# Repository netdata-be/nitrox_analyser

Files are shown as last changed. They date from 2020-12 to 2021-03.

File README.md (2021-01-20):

# Nitrox Anylyser

## BOM 

| # | Name | Price  |
|---|---|---|
| 1 | PCB custom made |  9,99  |
| 1 | Arduino Nano | 19,00  |
| 1 | ADS1115 | 14,95  |
| 1 | 1.3 inch OLED Display 128*64 pixels wit - I2C |  8,00  |
| 1 | MT3608 DC-DC Boost converter |  2,00  |
| 1 | Diode 1N4007 |  0,10  |
| 1 | 18650 Battery holder to solder |  1,50  |
| 1 | 18650 Battery with protection |  6,50  |
| 1 | Audio Jack 3,5mm (mono) 0,6m |  1,50  |
| 1 | 40 Pin header row |  0,40  |
| 1 | [O2 oxygen Cell (R-17VAN Oxygen Sensor) or other](https://www.vandagraph.com/index.php?main_page=product_info&cPath=5_8&products_id=30) | 79,00  |
| 1 | Spelsberg Kabeldoos abox 060-62 | 12,00  |
| 1 | On/Off button |  2,50  |
| 1 | Push Button |  2,50  |
| 1 | [B-50057 Flow Diverter](https://www.vandagraph.com/index.php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) |  5,00  |
| 1 | [Quick-Ox Sampler](https://www.vandagraph.com/index.php?main_page=product_info&products_id=20) | 22,00  |

Total cost: 194,95

The sensor, flow divertor, and Quick-Ox are high end quality products as they are needed for an accurate measurement.

## Functions 

* Auto calibrate iteself at boot to 20.9 oxygen
* Force a calibration by long pressing the button
* When measuring 100% o2 and forcing a calibration by a long press a second calibration point is stored ( 20,9% air ADN 100% ) 
  so compensating for the not fully linear scale.
* Each press on the button gives you an other page with info
  This page is saved to eeprom so if you shutdown and restart the analyzer the last page selected will be shown again.
* Battery monitor of the 18650 battery

## Screenshots of the different screens

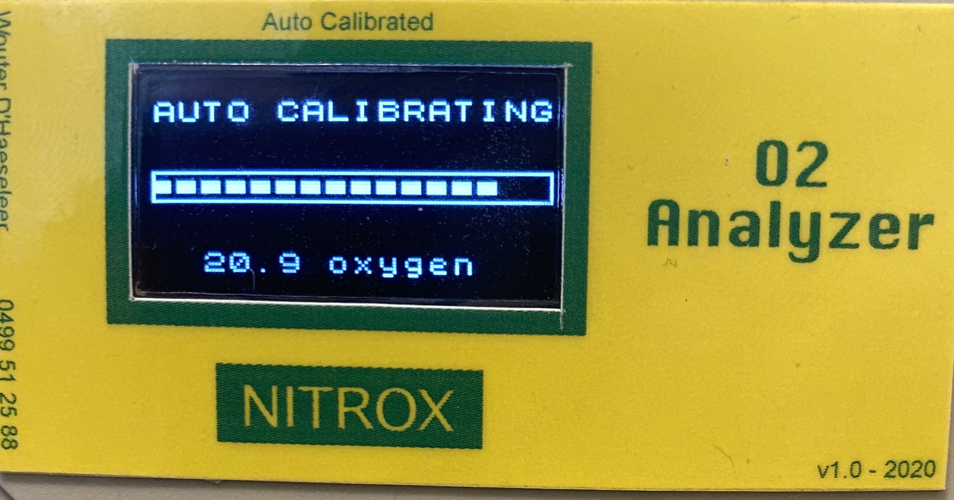
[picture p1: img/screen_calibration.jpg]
Calibration_screen


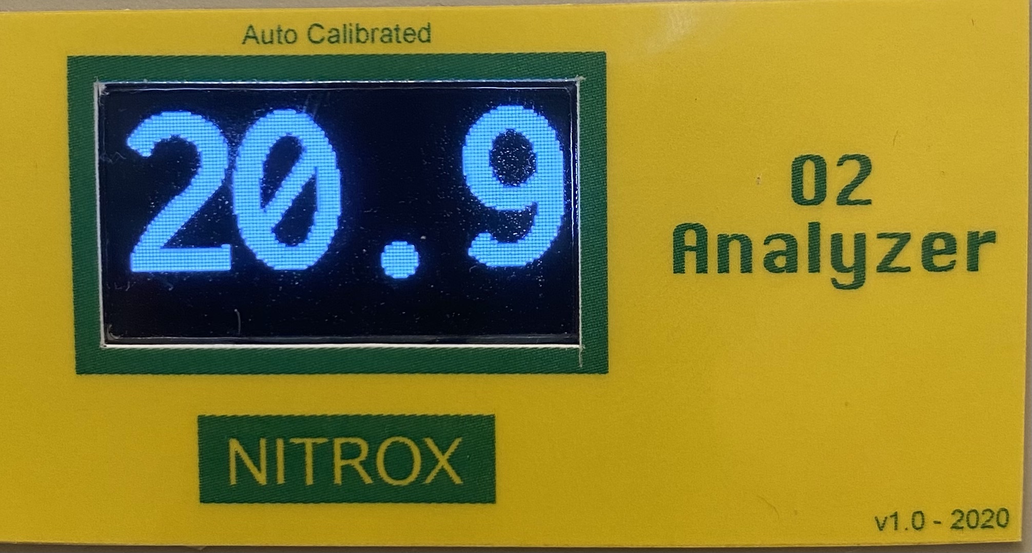
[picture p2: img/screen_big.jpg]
Big screen


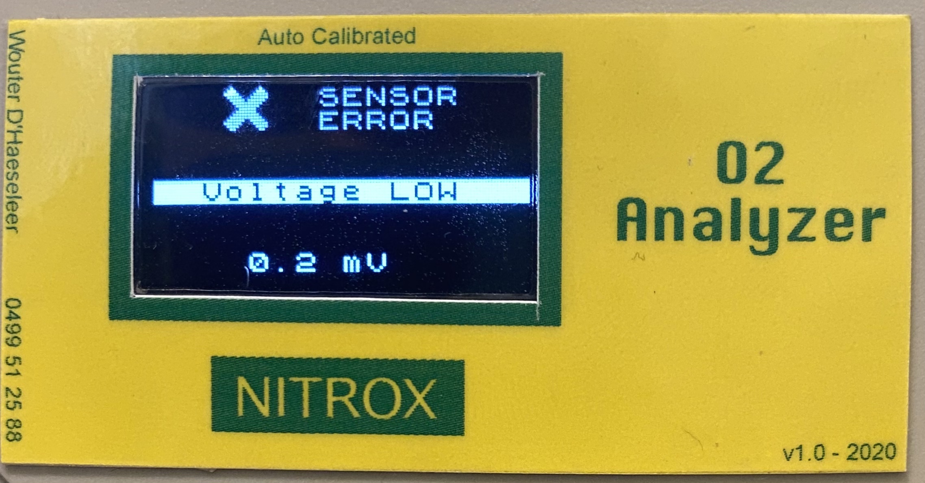
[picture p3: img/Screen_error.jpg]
Error screen


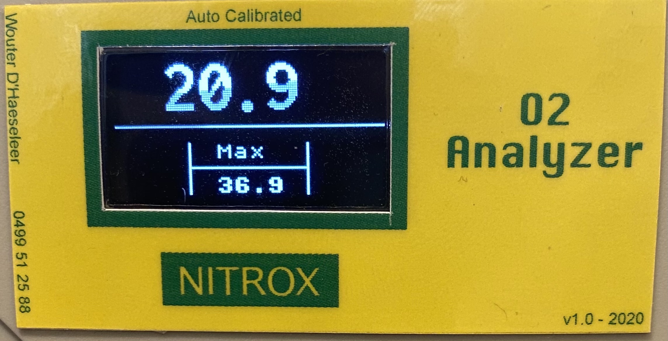
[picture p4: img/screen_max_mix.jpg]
Max screen


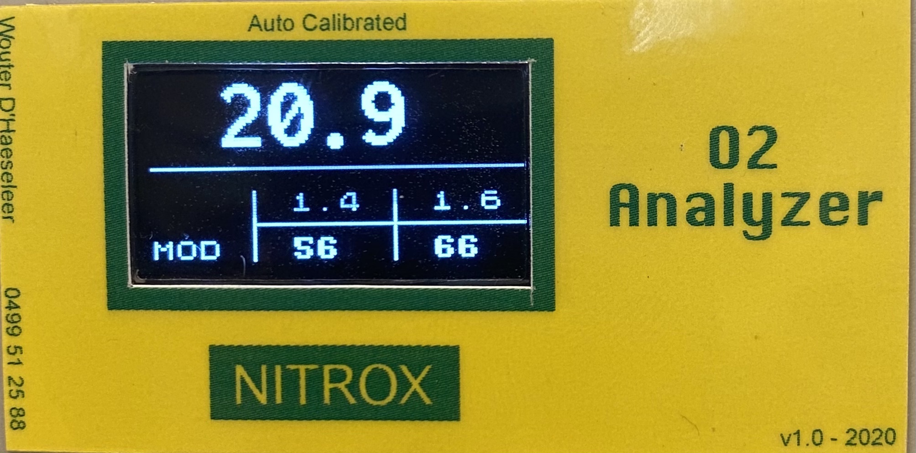
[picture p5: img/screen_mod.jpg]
MOD screen


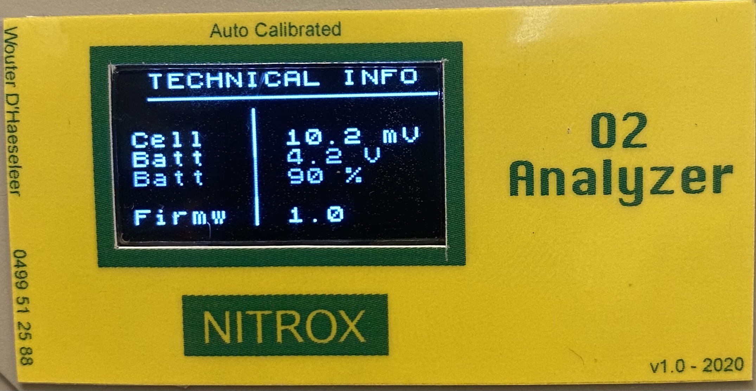
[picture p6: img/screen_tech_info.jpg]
Tech info screen


## PCB

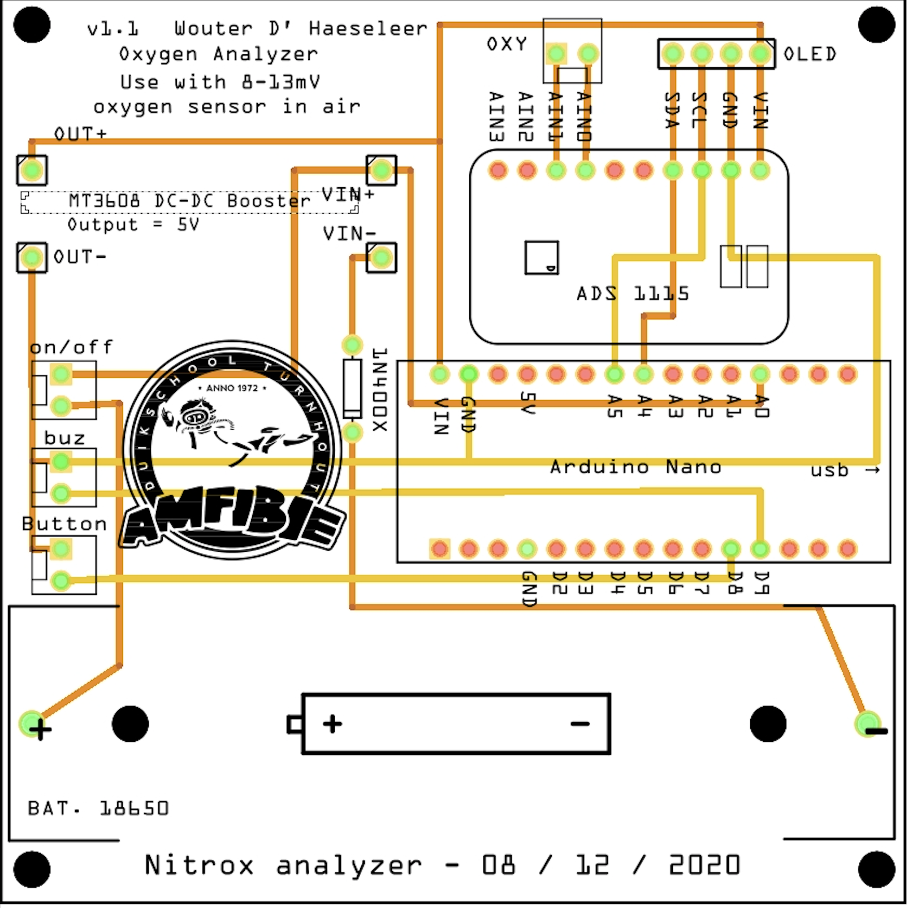
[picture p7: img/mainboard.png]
PCB


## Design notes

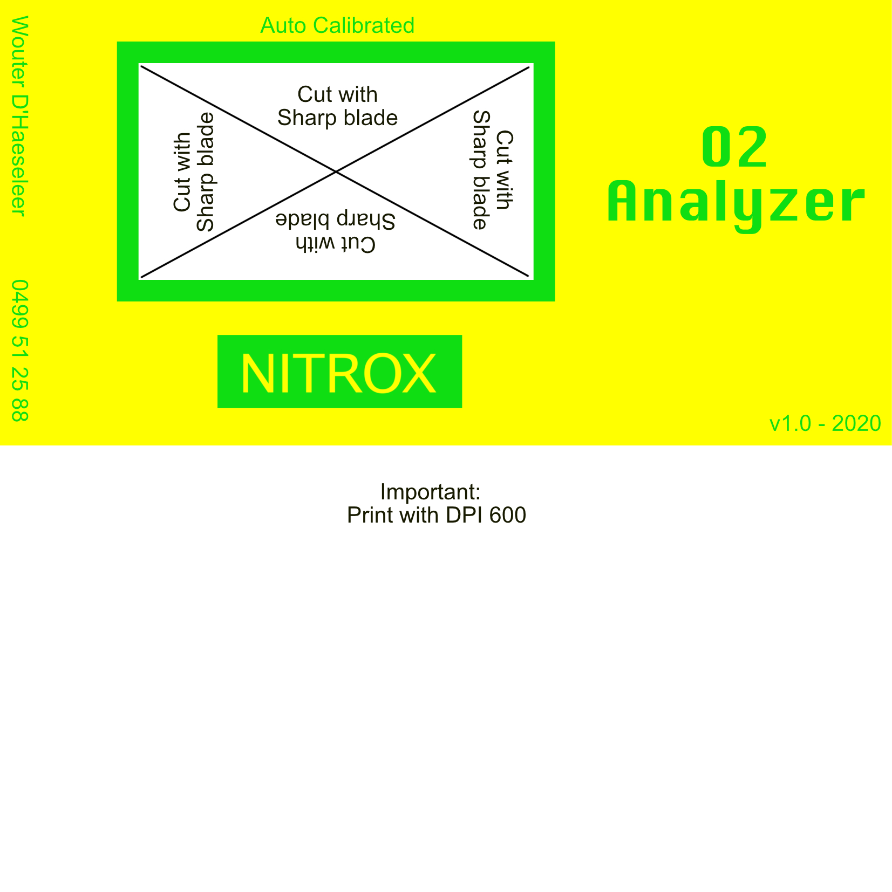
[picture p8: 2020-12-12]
Label_o2_anylaser.jpg

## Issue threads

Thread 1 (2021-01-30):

How to adjust the code to other sensors voltages?

jogomo, 2021-01-30:
Hi,

I apologize in advance if this is not the right place to ask.

I'm planning to build an nitrox analyzer based in your great project.

I already have 2 old DIY analyzers, based on PM128 LCD Panel Meter and these are the the sensors I've using for nearly 20 years, reliable and not very expensive: https://sumatec.de/gasmessung/sauerstoffsensoren/medical-sensors/3/m-25-med.-sensor
These sensors have an initial output signal of 9.0 to 14.5 mV @ dry ambient air.

Would you mind to point me to how to adjust the code to this voltage interval, instead of 8-13mV of the sensor you used?

Best regards.

jogomo, 2021-03-04:
I've built up the analyzer with my sensor with no issues.
Best.

Closed 2021-03-04.

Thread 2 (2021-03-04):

Display Change when touching D8 Cable

D-G-L, 2021-03-04:
Hi, I built up the Analyzer, works fine, but somehow the display changes everytime I just touch cable from D8 (Pushbutton connection to Arduino) even if its not even connected. It happens also when I even plug in the cable to D8.
I assume some shortcuts?

netdata-be, 2021-03-04:
This is indeed a bug, I need to use the `INPUT_PULLUP` instead of the `[INPUP](https://github.com/netdata-be/nitrox_analyser/blob/master/nitrox_analyzer.ino#L175)`

However this means that I should invert the behaviour as well.
I will try to fix this later this week.

Thanks for reporting.

D-G-L, 2021-03-04:
Just for info: Changing just to INPUT_PULLUP now starts a calibrating when you touch the button. If you touch it again fast after that, it changes the display as it should. But every new touch first starts calibrating. Try to work also through it TKS

netdata-be, 2021-03-04:
Indeed that is the behaviour I would expect, since changing to `INPUT_PULLUP`  inverts the Behaviour of the button.
To sum:

`INPUT`
* Button not pressed => LOW
* Button pressed => HIGH

`INPUT_PULLUP
* Button not pressed => High
* Button pressed => LOW

So the logic that detects the button press needs to inverted as well.

You can do that if you want and submit a Pull request, or I can do this later this week.

D-G-L, 2021-03-04:
Code changed, works now

netdata-be, 2021-03-04:
Thanks for the PR, I will link them so there is tracking.

Closed 2021-03-04.

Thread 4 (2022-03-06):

storage space error with Arduino Nano

Amir-SSDC, 2022-03-06:
Hi,
i'm using Arduino Nano as advised in the readme file, however when i try to upload the code it gives me the below error.

text section exceeds available space in boardSketch uses 31066 bytes (101%) of program storage space. Maximum is 30720 bytes.

Global variables use 1062 bytes (51%) of dynamic memory, leaving 986 bytes for local variables. Maximum is 2048 bytes.
Sketch too big; see https://support.arduino.cc/hc/en-us/articles/360013825179 for tips on reducing it.
Error compiling for board Arduino Nano.

Are you using Arduino Nano or something else?

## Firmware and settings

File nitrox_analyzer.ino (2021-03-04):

  
/*****************************************************************************
 * 
 * (c) 2020 Wouter D'Haeseleer <wouter@netdata.be>
 * 
 * o2 analyser - gasblender.org
 * source code derivated from ej's o2 oled analyzer - v0.21 (http://ejlabs.net/arduino-oled-nitrox-analyzer)  
 * 
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
 *****************************************************************************/

#include <SPI.h>
#include <Wire.h>
#include <EEPROM.h>
#include <Adafruit_ADS1015.h>
#include "RunningAverage.h"
#include <Arduino.h>
#include <U8x8lib.h>
#include <avr/wdt.h>

#define RA_SIZE 16
RunningAverage RA(RA_SIZE);
RunningAverage battVolt(20);

Adafruit_ADS1115 ads(0x48);

U8X8_SH1106_128X64_NONAME_HW_I2C u8x8(/* reset=*/ U8X8_PIN_NONE);


double barsize = RA_SIZE / 16.0 ;
double oxVair = 0;
double oxV1atm = 0;
double oxVmax = 0;


double result;
double oxVact = 0.0;

float multiplier;
byte previous = HIGH;
unsigned long firstTime; // how long since the button was first pressed
int battPcrt = 0;
char active = 0;
char bootcounter = 0;
char toggle = 0;
char errorState = 0;
char page = 0;
double result_max = 0;
uint8_t lijn_onder[8] = { 128,128,128,128,128,128,128,128};

uint8_t lijn_midden[8] = { 8,8,8,8,8,8,8,8};
uint8_t table_left[8] = { 0,0,0,255,8,8,8,8};
uint8_t table_right[8] = { 8,8,8,255,0,0,0,0};

uint8_t table_center[8] = { 8,8,8,255,8,8,8,8};

uint8_t lijn_boven[8] = { 1,1,1,1,1,1,1,1};
uint8_t lijn_links[8] = { 255,0,0,0,0,0,0,0};
uint8_t lijn_rechts[8] = { 0,0,0,0,0,0,0,255};

uint8_t middlebar[8] = { 60  ,60  ,60  ,60  ,60  ,60  ,0   ,0};
uint8_t firstbar[8]  = { 255 ,60  ,60  ,60  ,60  ,60  ,0  , 0};
uint8_t lastbar[8]   = { 60  ,60  ,60  ,60  ,60  ,60  ,0   ,255};

// if the voltage drops below or raises above these thresholds an error is shown
#define milivolt_low_error 6
#define milivolt_high_error 70

#define buttonPin 8
#define buzzer 9  // buzzer


int millis_held;    // How long the button was held (milliseconds)
int secs_held;      // How long the button was held (seconds)
int prev_secs_held; // How long the button was held in the previous check



float cal_mod (float percentage, float ppo2 = 1.4) {
  return 10 * ( (ppo2 / (percentage / 100)) - 1 ); 
}


void beep(int x = 1) { // make beep for x time

  for (int i = 0; i < x; i++) {
    tone(buzzer, 2800, 100);
    delay(200);
  }
  noTone(buzzer);
}


int read_sensor(int adc = 0) {
  int16_t millivolts = 0;
  double currentmv = 0;
  millivolts = ads.readADC_Differential_0_1();
  millivolts = abs(millivolts);

 
  RA.addValue(millivolts);

  currentmv = RA.getAverage();
  currentmv = abs(currentmv);
  return currentmv;

  /* debug  erics
   Serial.print("read_sensor o2: ");
   Serial.print(oxVact);
   Serial.print(" mV\n");
  */
  
  wdt_reset();
}

void setup(void) {
  
  Serial.begin(9600);
  Serial.print("Running: Setup\n");

  page   = EEPROMReadInt(1);
  oxVmax = EEPROMReadInt(2);


  // Init 
  u8x8.begin();     // Init the OLED
  ads.begin();      // ads1115 start
  RA.clear();       // Clear the Running Avarage
  battVolt.clear(); // Clear the Running Avarage


  /* power saving stuff for battery power */
  ACSR = B10000000;
  // Disable digital input buffers on all analog input pins
  DIDR0 = DIDR0 | B00111111;


  /*
    Here we can play with the gain of the ADS chip and its multiplier
    An o2 sensor hase a voltage in air between 7-13 mV
    And it's maximum is at 1bar O2 = 61.9mV
    And at the absuluut max of 3,5 Bar o2 it would be 175mV
    175mV is 0.175V
    
    With GAIN_SIXTEEN the max voltage is +/-0.256V 
    This is well above the the 0.175V
    And gives us the highest resulution
    1 bit = 0.125mV
    Examples found on the internet use GAIN_EIGHT
   */
  
  //ads.setGain(GAIN_TWO);
  //multiplier = 0.0625F;
               
  //ads.setGain(GAIN_EIGHT);u8x8.clearDisplay();
  //multiplier = 0.015625F;

  ads.setGain(GAIN_SIXTEEN);
  multiplier = 0.0078125F; 

  pinMode(buttonPin, INPUT_PULLUP);

  batteryMonitor();


   /*
  // Draw a bootscreen on the OLED
  u8x8.setFont(u8x8_font_inb21_2x4_r);
  u8x8.setInverseFont(1);
  u8x8.drawString(0,0,"         ");
  u8x8.drawString(0,1," NITROX  ");
  u8x8.setInverseFont(0);
  u8x8.setFont(u8x8_font_chroma48medium8_r);
  u8x8.drawString(0,5,"Wouter D'H v1.0");
  u8x8.drawString(6,7,"2020");
  delay(2000);
  */
  
  u8x8.clearDisplay();
  //Serial.print("Setup finished\n");



  beep(1);
}


// Write to the EEPROM 
// We use this to store data accross a reboot
void EEPROMWriteInt(int p_address, int p_value)
{
  byte lowByte = ((p_value >> 0) & 0xFF);
  byte highByte = ((p_value >> 8) & 0xFF);

  EEPROM.write(p_address, lowByte);
  EEPROM.write(p_address + 1, highByte);
}

unsigned int EEPROMReadInt(int p_address)
{
  byte lowByte = EEPROM.read(p_address);
  byte highByte = EEPROM.read(p_address + 1);

  return ((lowByte << 0) & 0xFF) + ((highByte << 8) & 0xFF00);
}

int calibrate(float oxGas) {
 
    //Serial.print("calibrating for sampleling gas : ");
    //Serial.print(oxGas);
    //Serial.print(" % Oxygen\n");
  

  // Clear the Running Avarage so we can start fresh
  RA.clear();
  
  u8x8.clearDisplay();
  u8x8.setFont(u8x8_font_chroma48medium8_r);
  u8x8.drawString(0,1,"AUTO CALIBRATING");


  
  u8x8.setFont(u8x8_font_chroma48medium8_r);


  u8x8.drawTile(0,3, 1, lijn_onder);
  u8x8.drawTile(1,3, 1, lijn_onder);
  u8x8.drawTile(2,3, 1, lijn_onder);  
  u8x8.drawTile(3,3, 1, lijn_onder);
  u8x8.drawTile(4,3, 1, lijn_onder);  
  u8x8.drawTile(5,3, 1, lijn_onder);
  u8x8.drawTile(6,3, 1, lijn_onder);
  u8x8.drawTile(7,3, 1, lijn_onder);
  u8x8.drawTile(8,3, 1, lijn_onder);
  u8x8.drawTile(9,3, 1, lijn_onder);
  u8x8.drawTile(10,3, 1, lijn_onder);
  u8x8.drawTile(11,3, 1, lijn_onder);
  u8x8.drawTile(12,3, 1, lijn_onder);
  u8x8.drawTile(13,3, 1, lijn_onder);
  u8x8.drawTile(14,3, 1, lijn_onder);
  u8x8.drawTile(15,3, 1, lijn_onder);

  u8x8.drawTile(0,4, 1, lijn_links);
  u8x8.drawTile(15,4, 1, lijn_rechts);

  u8x8.drawTile(0,5, 1, lijn_boven);
  u8x8.drawTile(1,5, 1, lijn_boven);
  u8x8.drawTile(2,5, 1, lijn_boven);  
  u8x8.drawTile(3,5, 1, lijn_boven);
  u8x8.drawTile(4,5, 1, lijn_boven);  
  u8x8.drawTile(5,5, 1, lijn_boven);
  u8x8.drawTile(6,5, 1, lijn_boven);
  u8x8.drawTile(7,5, 1, lijn_boven);
  u8x8.drawTile(8,5, 1, lijn_boven);
  u8x8.drawTile(9,5, 1, lijn_boven);
  u8x8.drawTile(10,5, 1, lijn_boven);
  u8x8.drawTile(11,5, 1, lijn_boven);
  u8x8.drawTile(12,5, 1, lijn_boven);
  u8x8.drawTile(13,5, 1, lijn_boven);
  u8x8.drawTile(14,5, 1, lijn_boven);
  u8x8.drawTile(15,5, 1, lijn_boven);


  u8x8.setCursor(2, 7);
  u8x8.print(oxGas);
  u8x8.print(" oxygen");

  double result;

  
  int bar = 1;
  
  for (int cx = 0; cx <= RA_SIZE; cx++) {
    u8x8.setFont(u8x8_font_chroma48medium8_r);
    
    if(cx >= (barsize*bar)) {

      switch (bar) {
        case 1:
          u8x8.drawTile(bar-1,4, 1, firstbar);
          break;
        case 16:
          u8x8.drawTile(bar-1,4, 1, lastbar);
          break;
        default:
          u8x8.drawTile(bar-1,4, 1, middlebar);
          break;
      }
      bar = bar+1;
    }
    result = read_sensor(0);
    delay(50);
  }
  result = RA.getAverage();
  result = abs(result);
  
  //Serial.print("Calibration value o2: ");
  //Serial.print(result);
  //Serial.print("\n");


   

  if (result <= milivolt_low_error) {
    errorState=1;
    return 0;
  } else {
    u8x8.clearDisplay();
    active = 0;

    if ( oxGas == 20.9 ) {

      // This is the 100% linear value of the milivolts expected
      // From the sensor in 1 bar o2 == 100 % oxygen
      oxV1atm = 1/0.209 * result * multiplier;

      //Serial.print("Theoretical linear 100% o2 voltage level: ");
      //Serial.print(oxV1atm);
      //Serial.print(" mV \n");
      
    } else if ( oxGas == 100.0 ) {
      //Serial.print("Voltage level for 100% o2 : ");
      //Serial.print(result * multiplier);
      //Serial.print(" mV \n");
      EEPROMWriteInt(2, result);
    }
    return result;
  }
}

void error(int e) {


  oxVact = read_sensor(0);
  oxVact = oxVact * multiplier;





  

  // Serial.print("mv = ");
  // Serial.print(oxVact);
  // Serial.print("\n");


  u8x8.setFont( u8x8_font_open_iconic_check_2x2 );
  u8x8.drawString(3,1,"D");
  u8x8.setFont(u8x8_font_chroma48medium8_r);
  u8x8.drawString(7,1,"SENSOR");
  u8x8.drawString(7,2,"ERROR");
    

  u8x8.setInverseFont(1);

  if ( e == 1 ) {
     u8x8.drawString(0,4,"  Voltage LOW   ");
   } else if ( e == 2 ) {
     u8x8.drawString(0,4,"  Voltage High   ");
   } else {
     u8x8.drawString(0,4,"  Unknown Err   ");
   }  
  
  u8x8.setInverseFont(0);

  u8x8.setCursor(3, 7);
  u8x8.print(oxVact , 2);
  u8x8.print(" mV ");

  if (oxVact > milivolt_low_error && oxVact < milivolt_high_error ) {
    errorState = 0;
    oxVair = 0;
    result_max = 0;
  } 
}

byte countDigits(int num){
  byte count=0;
  while(num){
    num=num/10;
    count++;
  }
  return count;
}

void batteryMonitor() {
  int battVolt_Value = analogRead(A0);
  battVolt.addValue(battVolt_Value * (5.0 / 1023.0));
  float volt = battVolt.getAverage();
 
  if ( volt >= 4.1 )  {
    battPcrt = 100;
  }
  if ( volt < 4.1 && volt >=  4.0 ) {
    battPcrt = 90;
  }
  if ( volt < 4.0 && volt >=  3.9 ) {
    battPcrt = 80;
  }
  if ( volt < 3.9 && volt >=  3.8 ) {
    battPcrt = 70;
  }
  if ( volt < 3.8 && volt >=  3.7 ) {
    battPcrt = 60;
  }
  if ( volt < 3.7 && volt >=  3.6 ) {
    battPcrt = 20;
  }
  if ( volt < 3.6 && volt >=  3.5 ) {
    battPcrt = 10;
  }
  if ( volt < 3.5 ) {
    battPcrt = 0;
  }
}

void header(float result) {
      u8x8.setFont(u8x8_font_inb21_2x4_r);      
      u8x8.setCursor(3, 0);
      u8x8.print(result, 1);

      // Draw a lin under the result
      u8x8.drawTile(0,4, 1, lijn_boven);
      u8x8.drawTile(1,4, 1, lijn_boven);
      u8x8.drawTile(2,4, 1, lijn_boven);
      u8x8.drawTile(3,4, 1, lijn_boven);
      u8x8.drawTile(4,4, 1, lijn_boven);
      u8x8.drawTile(5,4, 1, lijn_boven);
      u8x8.drawTile(6,4, 1, lijn_boven);
      u8x8.drawTile(7,4, 1, lijn_boven);
      u8x8.drawTile(8,4, 1, lijn_boven);
      u8x8.drawTile(9,4, 1, lijn_boven);
      u8x8.drawTile(10,4, 1, lijn_boven);
      u8x8.drawTile(11,4, 1, lijn_boven);
      u8x8.drawTile(12,4, 1, lijn_boven);
      u8x8.drawTile(13,4, 1, lijn_boven);
      u8x8.drawTile(14,4, 1, lijn_boven);
      u8x8.drawTile(15,4, 1, lijn_boven);

      u8x8.setFont(u8x8_font_chroma48medium8_r);
}

void analysing(int x, int cal, int cal100) {
  int mod = 0;
  

  float oxVact = read_sensor(0);




  //Serial.print("Oxygen = ");   
  if (cal100 > 0 ) {

 
   result = 20.9 + 79.1*(oxVact - cal)/(cal100 - cal);
   //Serial.print(result);    
   //Serial.print(" %  - Calibrated at air and 100% o2\n");   
  } else {
   result = (float(oxVact)/float(cal) )*20.9; 
   //Serial.print(result);    
   //Serial.print(" %  - Calibrated only on air\n");   
  }

  oxVact = oxVact*multiplier;


  if (result > 99.9) result = 99.9;


  if (oxVact < milivolt_low_error || result <= 0  ) {
    u8x8.clearDisplay();
    errorState=1;
  } else if ( oxVact > milivolt_high_error ) {
    u8x8.clearDisplay();
    errorState=2; 
  } else {
    u8x8.setFont(u8x8_font_chroma48medium8_r);

    if (result >= result_max) {
      result_max = result;
    }




    if ( page == 0 ) {

      header(result);


      u8x8.setCursor(4, 5);
      u8x8.print("| Max  |");

      u8x8.drawTile(4,6, 1, table_left);
      u8x8.drawTile(5,6, 1, lijn_midden);
      u8x8.drawTile(6,6, 1, lijn_midden);
      u8x8.drawTile(7,6, 1, lijn_midden);
      u8x8.drawTile(8,6, 1, lijn_midden);
      u8x8.drawTile(9,6, 1, lijn_midden);
      u8x8.drawTile(10,6, 1, lijn_midden);
      u8x8.drawTile(11,6, 1, table_right);


      u8x8.setCursor(4, 7);
      u8x8.print("|");
      u8x8.setCursor(11, 7);
      u8x8.print("|");
      u8x8.setCursor(6, 7);

      u8x8.setFont(u8x8_font_amstrad_cpc_extended_n);

      u8x8.print(result_max, 1);
      u8x8.print(" ");


      
    }


    // MOD Display
    if ( page == 1 ) {

      header(result);


      // Print table with MOD 1.4 and 1.6 ppO2
      u8x8.setCursor(4, 5);
      u8x8.print("| 1.4 | 1.6 ");

      u8x8.drawTile(4,6, 1, table_left);
      u8x8.drawTile(5,6, 1, lijn_midden);
      u8x8.drawTile(6,6, 1, lijn_midden);
      u8x8.drawTile(7,6, 1, lijn_midden);
      u8x8.drawTile(8,6, 1, lijn_midden);
      u8x8.drawTile(9,6, 1, lijn_midden);
      u8x8.drawTile(10,6, 1, table_center);
      u8x8.drawTile(11,6, 1, lijn_midden);
      u8x8.drawTile(12,6, 1, lijn_midden);
      u8x8.drawTile(13,6, 1, lijn_midden);
      u8x8.drawTile(14,6, 1, lijn_midden);
      u8x8.drawTile(15,6, 1, lijn_midden);

      u8x8.setCursor(0, 7);
      u8x8.print("MOD | ");

      u8x8.setFont(u8x8_font_amstrad_cpc_extended_n);
      u8x8.print(floor(cal_mod(result, 1.4)),0);
      u8x8.print(" ");

      u8x8.setFont(u8x8_font_chroma48medium8_r);
      u8x8.setCursor(10, 7);
      u8x8.print("|");

      u8x8.setFont(u8x8_font_amstrad_cpc_extended_n);
      u8x8.setCursor(12, 7);
      u8x8.print(floor(cal_mod(result, 1.6)),0);
      u8x8.print(" ");      
    }


    // Display Only large result
    if ( page == 2 ) {
      u8x8.setFont(u8x8_font_inb46_4x8_n);  
      u8x8.setCursor(0, 0);
      u8x8.print((float) result, 1);   
    }

    // Page with technical info
    // This page is NOT saved to EEPROM
    if ( page == 3 ) {

      u8x8.setCursor(0, 0);
      u8x8.print(" TECHNICAL INFO");
      u8x8.setCursor(0, 1);
      
      u8x8.drawTile(1,1, 1, lijn_midden);
      u8x8.drawTile(2,1, 1, lijn_midden);
      u8x8.drawTile(3,1, 1, lijn_midden);
      u8x8.drawTile(4,1, 1, lijn_midden);
      u8x8.drawTile(5,1, 1, lijn_midden);
      u8x8.drawTile(6,1, 1, lijn_midden);
      u8x8.drawTile(7,1, 1, lijn_midden);
      u8x8.drawTile(8,1, 1, lijn_midden);
      u8x8.drawTile(9,1, 1, lijn_midden);
      u8x8.drawTile(10,1, 1, lijn_midden);
      u8x8.drawTile(11,1, 1, lijn_midden);
      u8x8.drawTile(12,1, 1, lijn_midden);
      u8x8.drawTile(13,1, 1, lijn_midden);
      u8x8.drawTile(14,1, 1, lijn_midden);
      u8x8.drawTile(15,1, 1, lijn_midden);
      


      u8x8.setCursor(6, 2);
      u8x8.print("|");

      u8x8.setCursor(0, 3);

      u8x8.print("Cell  | ");
      u8x8.print( oxVact , 2); 
      u8x8.print(" mV");

      u8x8.setCursor(0, 4);
      u8x8.print("Batt  | ");
      u8x8.print(battVolt.getAverage() , 2);
      u8x8.print(" V ");

      u8x8.setCursor(0, 5);
      u8x8.print("Batt  | ");
      u8x8.print(battPcrt);
      u8x8.print(" % ");


      u8x8.setCursor(0, 6);
      if (cal100 > 0 ) {
        u8x8.print("refmix| Air + o2");
      } else {
        u8x8.print("refmix| Air    ");
      }
      u8x8.setCursor(0, 7);
      u8x8.print("Firmw | 1.2");
    }
  }
}


void max_clear() {
  result_max = 0;
  beep(1);
  battVolt.clear();
  active = 0;
}



void loop(void) {
  // Enable the Watchdog
  // Reset arduino if watchdog did not receive a reset after 8 seconds
  wdt_enable(WDTO_8S);
  batteryMonitor();

 
 int current = digitalRead(buttonPin);
 
  if (current == LOW && previous == HIGH && (millis() - firstTime) > 200) {
    firstTime = millis();
  }

  millis_held = (millis() - firstTime);


  if (millis_held > 2) {
    if (current == HIGH && previous == LOW) {
      if (millis_held <= 400) {
        
        page++;
        if ( page >= 4 ) {
          page = 0;
        }

        if ( page != 3 ) { 
          EEPROMWriteInt(1, page);
        }
        
        u8x8.clearDisplay();
      }
      if (millis_held >= 400 && millis_held < 5000 ) {



        // Check if the measured mV is high enough to calibrate on 100% oxygen
        // We allow a difference of 10mV to callibrate to 100%
        // Save it to the memroy, we only need to do this once in a while
        int oxVact = read_sensor(0);
        oxVact = oxVact*multiplier;
        
        if ( (oxVact > (oxV1atm - 10) ) &&  oxVair > 0) {
          oxVmax = calibrate(100.0);
        }else {
          max_clear();
          oxVair = calibrate(20.9);
        }
      }
      
      if (millis_held >= 5000 ) {
         //Serial.print("Clear  100% o2\n");
         max_clear();
         oxVmax=0;
         EEPROMWriteInt(2, 0);
         oxVair = calibrate(20.9);
      }
      
    }
  }


  previous = current;
  prev_secs_held = secs_held;

  if ( errorState > 0 ) {
    error(errorState);
  } else { 
    //calibration forced on boot
    if (oxVair == 0) {
      oxVair = calibrate(20.9);
    }

    analysing(0, oxVair, oxVmax);
  }
  wdt_reset();
  active++;
}

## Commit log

2020-12-12 Initial seed
    [mainboard.fzz]
2020-12-18 Updating BOM
2021-01-08 Adding cost for flow divertor
2021-01-09 Fixing battery monitor + make error more readable
    [nitrox_analyzer.ino]
2021-03-04 Update nitrox_analyzer.ino
    Line 175:
    INPUT
    Button not pressed => LOW
    Button pressed => HIGH
    INPUT_PULLUP
    Button not pressed => High
    Button pressed => LOW
    Logic reversed in Lines 660
    if (current == LOW && previous == HIGH &&
    and
    Line 668:
    if (current == HIGH && previous == LOW)
    [nitrox_analyzer.ino]

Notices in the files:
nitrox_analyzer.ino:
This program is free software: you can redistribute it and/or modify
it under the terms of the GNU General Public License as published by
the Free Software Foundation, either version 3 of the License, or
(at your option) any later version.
